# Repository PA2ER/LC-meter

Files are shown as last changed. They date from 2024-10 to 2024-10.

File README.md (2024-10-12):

# LC-meter
## Description
induction and capacity meter with pic controller.
*  Work in progress!!!
*  Finished version V1.0 of the PCB.
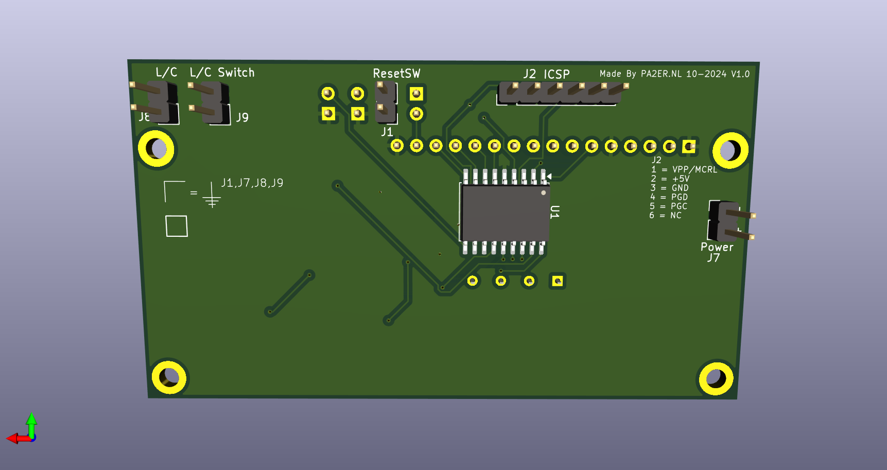
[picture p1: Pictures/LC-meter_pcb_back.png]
Backside of the PCB
 
 Back side of the PCB.
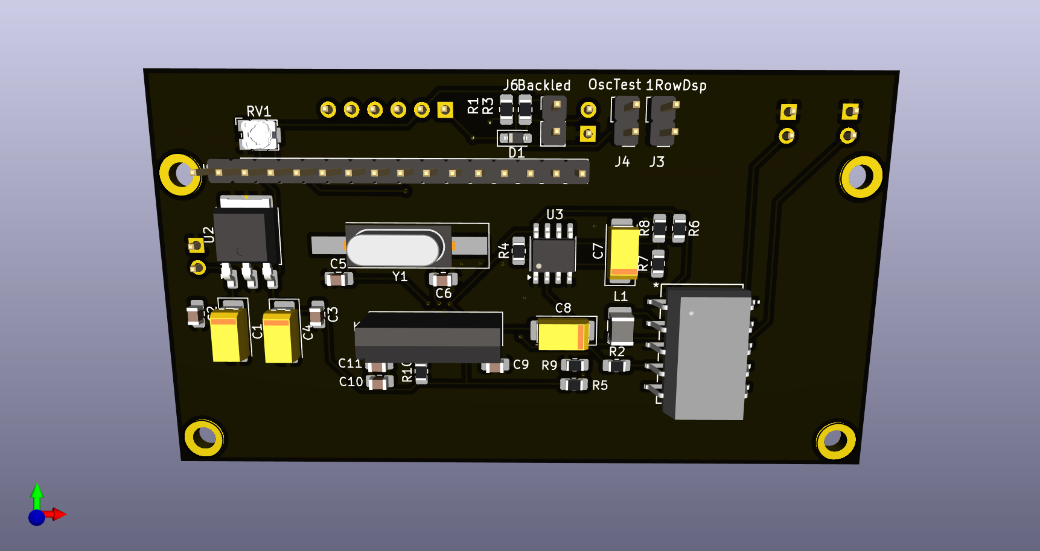
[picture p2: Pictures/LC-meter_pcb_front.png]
Front side of the PCB
 
 Front side of the PCB.
## Schematics
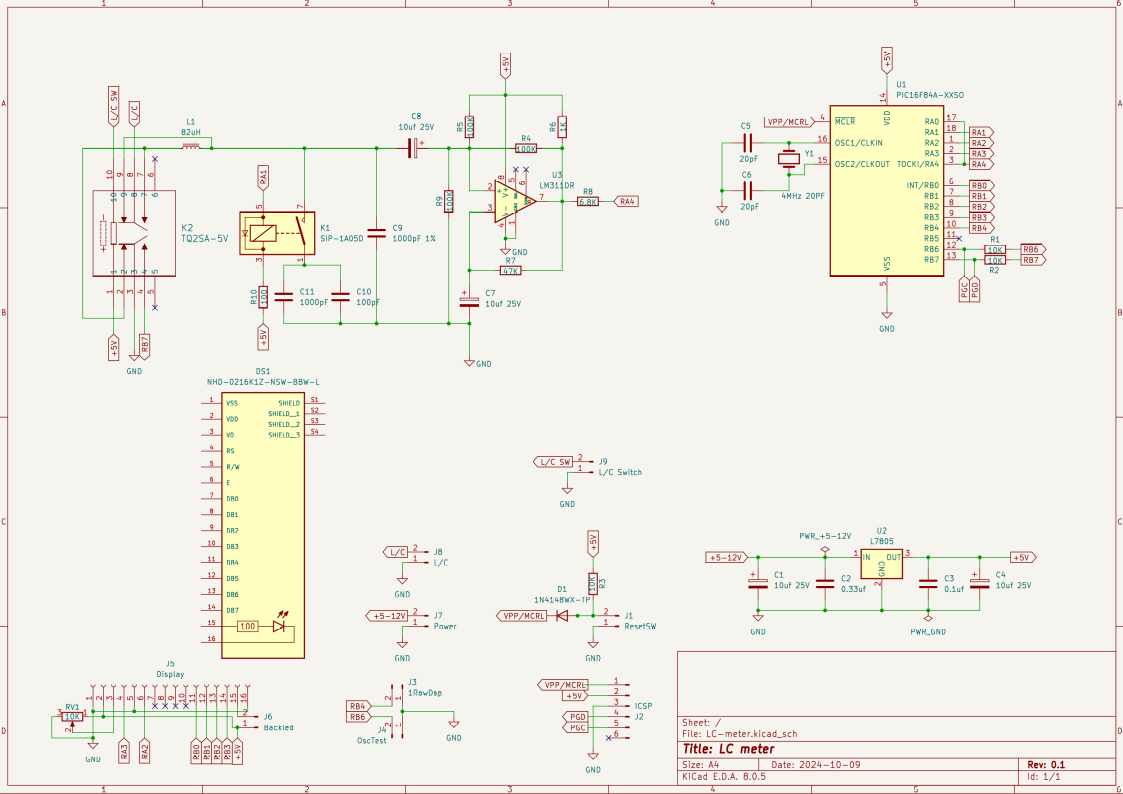
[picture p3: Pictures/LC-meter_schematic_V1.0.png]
schematic_v1
  
<!--stackedit_data:
eyJoaXN0b3J5IjpbLTg0MDYxMjgyM119
-->

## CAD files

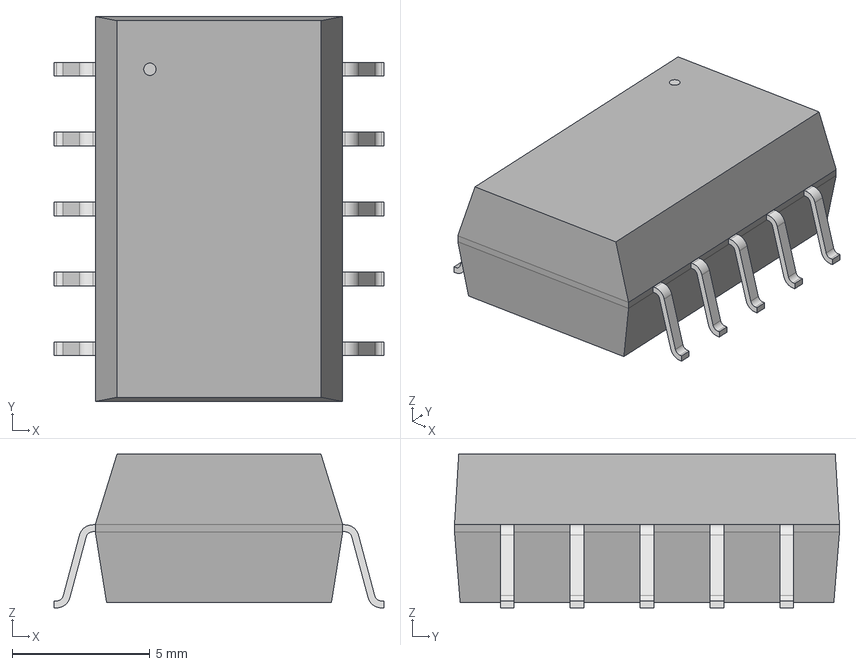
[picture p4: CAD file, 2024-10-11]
RELAY_TQ2_SA_PAN.step
12.0 x 14.0 x 5.59 mm

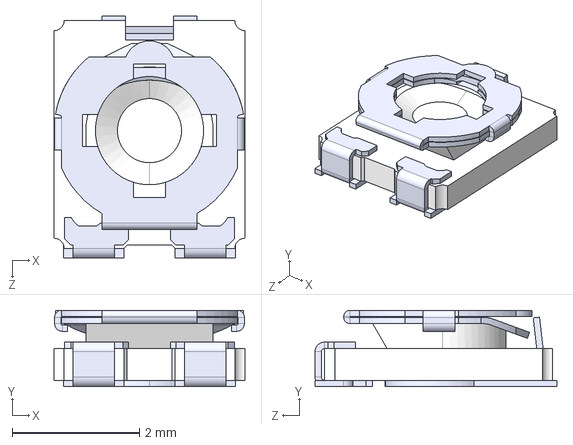
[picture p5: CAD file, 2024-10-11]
TC33X-2-333E.step
3.00 x 1.20 x 3.80 mm

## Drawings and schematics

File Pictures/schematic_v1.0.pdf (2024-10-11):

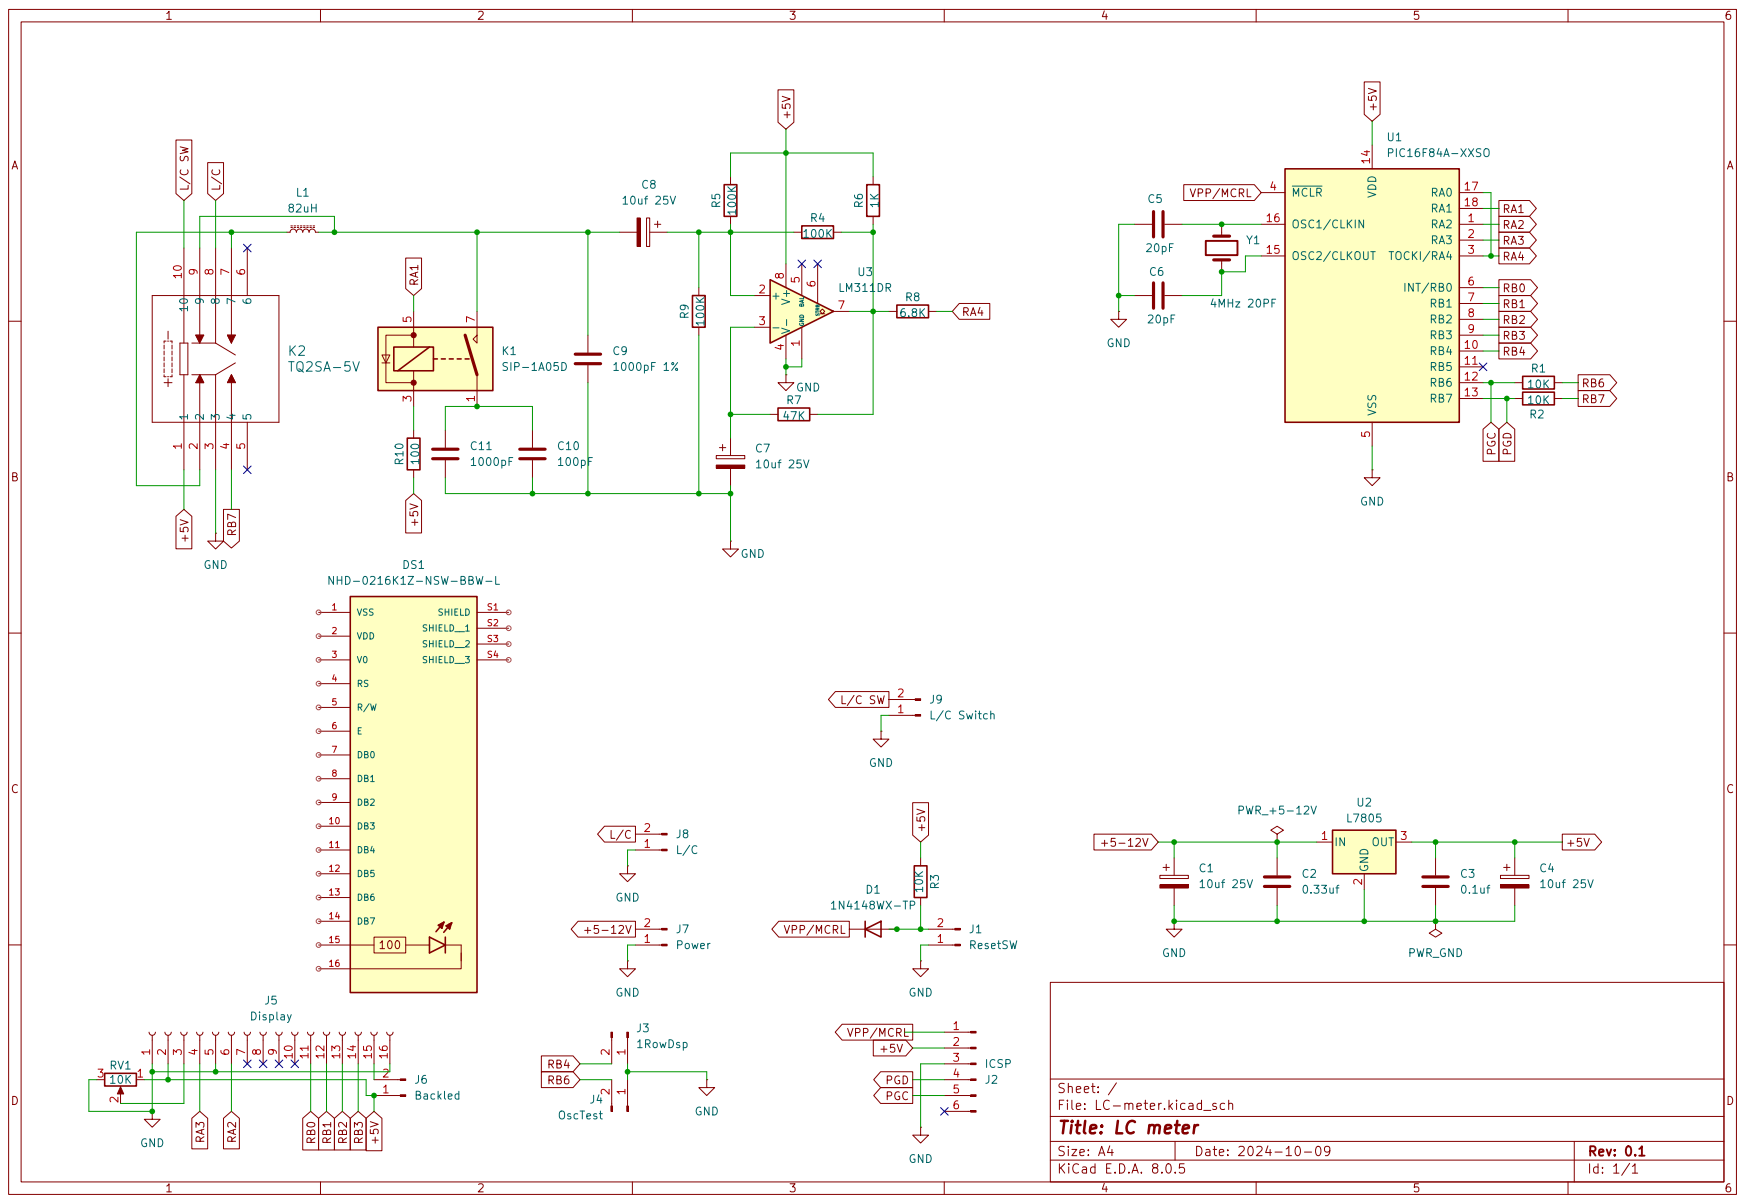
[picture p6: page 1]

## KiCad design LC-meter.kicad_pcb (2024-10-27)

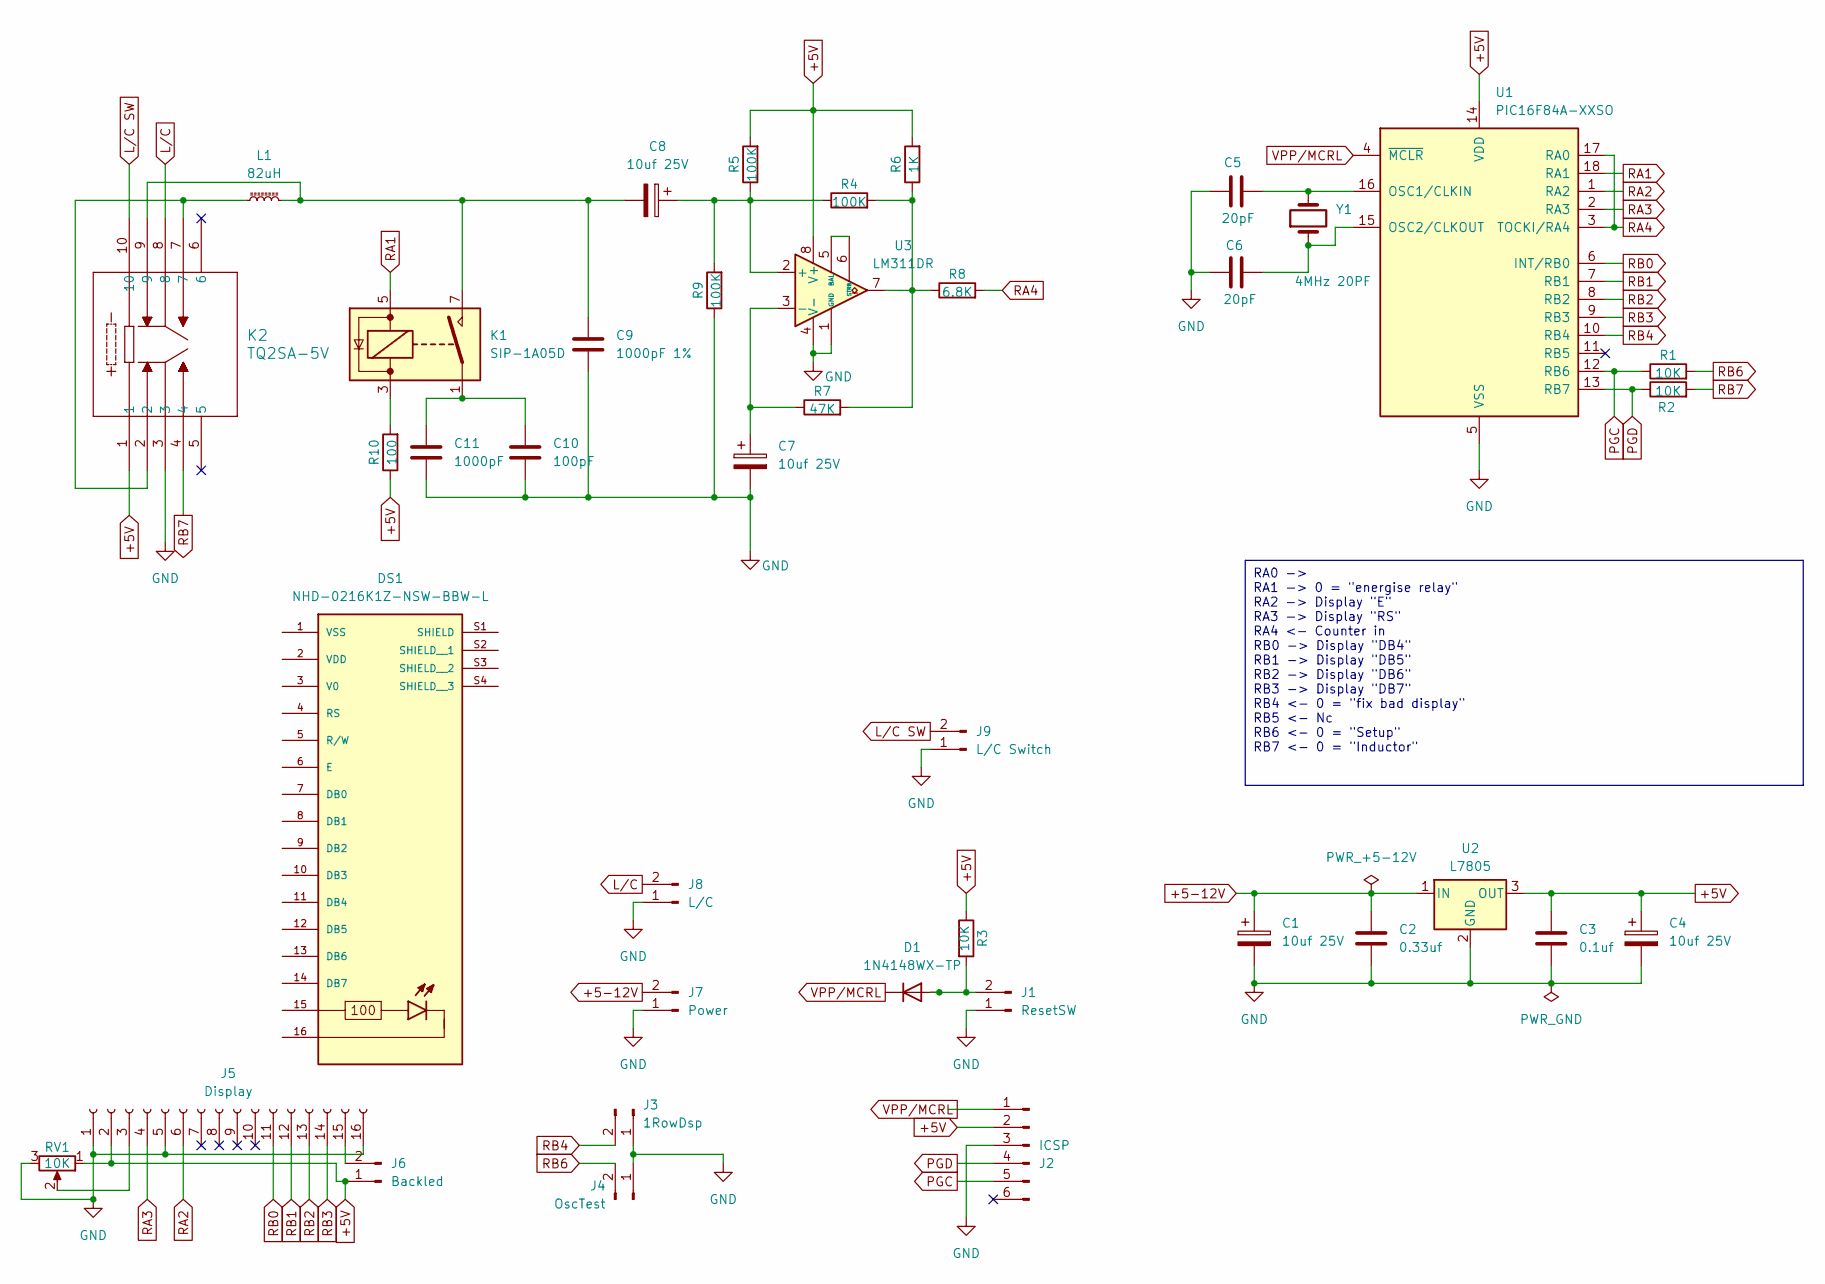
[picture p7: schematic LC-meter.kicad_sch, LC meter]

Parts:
C1, C4, C7, C8: 10uf 25V; CP_EIA-6032-28_Kemet-C_Pad2.25x2.35mm_HandSolder; Digikey 293D106X0025C2TE3
C2: 0.33uf; C_0805_2012Metric_Pad1.18x1.45mm_HandSolder; Digikey CC0805KKX7R8BB334
C3: 0.1uf; C_0805_2012Metric_Pad1.18x1.45mm_HandSolder; Digikey CC0805KRX7R9BB104
C5, C6: 20pF; C_0805_2012Metric_Pad1.18x1.45mm_HandSolder; Digikey C0805C200J5HAC7800
C9: 1000pF 1%; C_0805_2012Metric_Pad1.18x1.45mm_HandSolder; Digikey CC0805FRNPO9BN102
C10: 100pF; C_0805_2012Metric_Pad1.18x1.45mm_HandSolder; Digikey CC0805FRNPO9BN101
C11: 1000pF; C_0805_2012Metric_Pad1.18x1.45mm_HandSolder; Digikey CC0805FRNPO9BN102
D1: 1N4148WX-TP; D_SOD-323_HandSoldering; Digikey 1N4148WX-TP
DS1: NHD-0216K1Z-NSW-BBW-L; NHD_NHD-0216K1Z-NSW-BBW-L; PARTREV 03/28/17
J1: ResetSW; PinHeader_1x02_P2.54mm_Vertical
J2: ICSP; PinHeader_1x06_P2.54mm_Vertical
J3: 1RowDsp; PinHeader_1x02_P2.54mm_Vertical
J4: OscTest; PinHeader_1x02_P2.54mm_Vertical
J5: Display; PinHeader_1x16_P2.54mm_Vertical
J6: Backled; PinHeader_1x02_P2.54mm_Vertical
J7: Power; PinHeader_1x02_P2.54mm_Vertical
J8: L/C; PinHeader_1x02_P2.54mm_Vertical
J9: L/C Switch; PinHeader_1x02_P2.54mm_Vertical
K1: SIP-1A05D; Relay_SPST_StandexMeder_MS_Form1AB; Digikey SIP-1A05D
K2: TQ2SA-5V; RELAY_TQ2_SA_PAN-L
L1: 82uH; L_1210_3225Metric_Pad1.42x2.65mm_HandSolder; Digikey NLV32T-820J-EF
R1, R2, R3: 10K; R_0805_2012Metric_Pad1.20x1.40mm_HandSolder
R4, R5, R9: 100K; R_0805_2012Metric_Pad1.20x1.40mm_HandSolder
R6: 1K; R_0805_2012Metric_Pad1.20x1.40mm_HandSolder
R7: 47K; R_0805_2012Metric_Pad1.20x1.40mm_HandSolder
R8: 6.8K; R_0805_2012Metric_Pad1.20x1.40mm_HandSolder
R10: 100; R_0805_2012Metric_Pad1.20x1.40mm_HandSolder
RV1: 10K; Potentiometer_Bourns_TC33X_Vertical; Digikey TC33X-2-103E
U1: PIC16F84A-XXSO; SOIC-18W_7.5x11.6mm_P1.27mm; Digikey PIC16F84A-04/SO-ND
U2: L7805; TO-252-3_TabPin2; Digikey AS7805ADTR-G1DI
U3: LM311DR; SOIC-8_3.9x4.9mm_P1.27mm; Digikey IC COMPARATOR 1 GEN PUR 8SOIC
Y1: 4MHz 20PF; Crystal_SMD_HC49-SD_HandSoldering; Digikey 4M20P2/49SMT

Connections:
+5-12V: C1.1, C2.1, J7.2, U2.1 (IN)
+5V: C3.1, C4.1, J2.2, J5.2, J6.1, K2.1, R3.1, R5.2, R6.2, R10.1, RV1.1, U1.14 (VDD), U2.3 (OUT), U3.8 (V+)
GND: C1.2, C2.2, C3.2, C4.2, C5.1, C6.1, C7.2, C9.2, C10.2, C11.2, J1.1, J2.3, J3.1, J4.1, J5.1, J5.5, J5.16, J7.1, J8.1, J9.1, K2.3, R9.1, RV1.3, U1.5 (VSS), U2.2 (GND), U3.1 (GND), U3.4 (V-)
L/C: J8.2, K2.8
L/C SW: J9.2, K2.10
unnamed: C8.2, C9.1, K1.7, K2.9, L1.2
unnamed: C10.1, C11.1, K1.1
unnamed: D1.2 (A), J1.2, R3.2
unnamed: J5.3, RV1.2
unnamed: J5.15, J6.2
unnamed: K1.3, R10.2
unnamed: K2.2, K2.7, L1.1
unnamed: R4.2, R6.1, R7.2, R8.1, U3.7
unnamed: C5.2, U1.16 (OSC1/CLKIN), Y1.2
unnamed: C6.2, U1.15 (OSC2/CLKOUT), Y1.1
unnamed: C8.1, R4.1, R5.1, R9.2, U3.2 (+)
unnamed: C7.1, R7.1, U3.3 (-)
unnamed: U3.5 (BAL), U3.6 (STRB)
PGC: J2.5, R1.1, U1.12 (RB6)
PGD: J2.4, R2.1, U1.13 (RB7)
RA1: K1.5, U1.18 (RA1)
RA2: J5.6, U1.1 (RA2)
RA3: J5.4, U1.2 (RA3)
RA4: R8.2, U1.3 (TOCKI/RA4), U1.17 (RA0)
RB0: J5.11, U1.6 (INT/RB0)
RB1: J5.12, U1.7 (RB1)
RB2: J5.13, U1.8 (RB2)
RB3: J5.14, U1.9 (RB3)
RB4: J3.2, U1.10 (RB4)
RB6: J4.2, R1.2
RB7: K2.4, R2.2
VPP/MCRL: D1.1 (K), J2.1, U1.4 (~MCLR)

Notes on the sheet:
RA0 -> RA1 -> 0 = "energise relay" RA2 -> Display "E" RA3 -> Display "RS" RA4 <- Counter in RB0 -> Display "DB4" RB1 -> Display "DB5" RB2 -> Display "DB6" RB3 -> Display "DB7" RB4 <- 0 = "fix bad display" RB5 <- Nc RB6 <- 0 = "Setup" RB7 <- 0 = "Inductor"

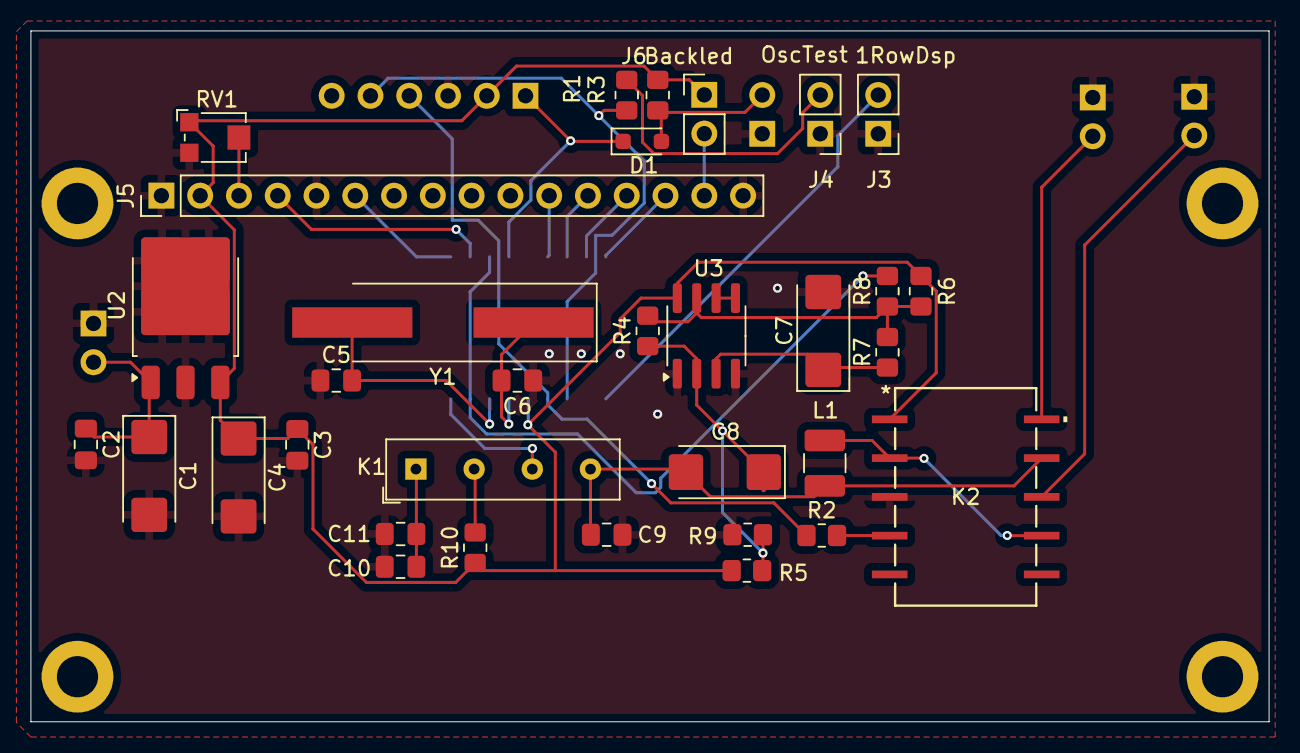
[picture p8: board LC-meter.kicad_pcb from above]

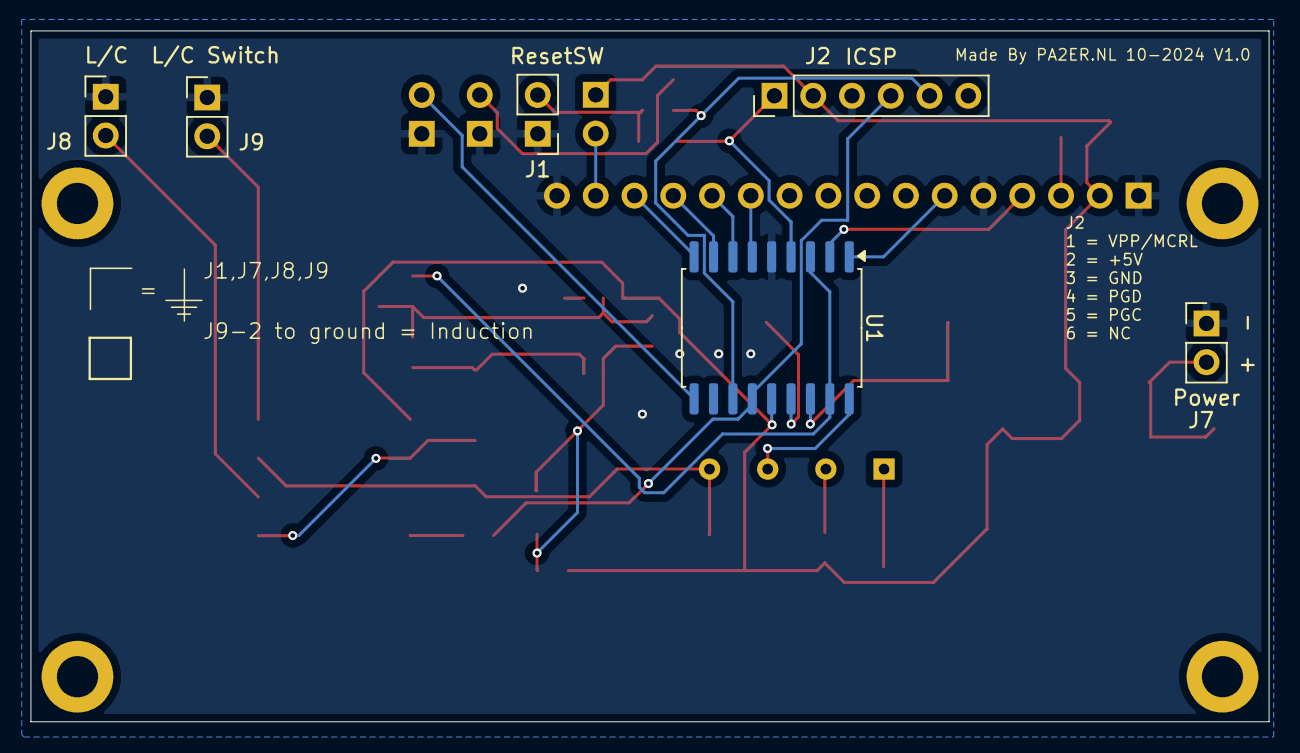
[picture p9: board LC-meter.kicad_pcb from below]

Board: 2 copper layers, 81.1 x 45.2 mm, 39 parts (6 on the bottom side), 32 nets.

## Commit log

2024-10-09 add display
    [LC-meter.kicad_pcb, LC-meter.kicad_sch]
2024-10-11 11-10-2024 PCB ready
    [LC-meter.kicad_pcb, LC-meter.kicad_sch, RELAY_TQ2_SA_PAN.step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]
2024-10-27 Update 23-10-2024
    [LC-meter.kicad_pcb, LC-meter.kicad_sch]
